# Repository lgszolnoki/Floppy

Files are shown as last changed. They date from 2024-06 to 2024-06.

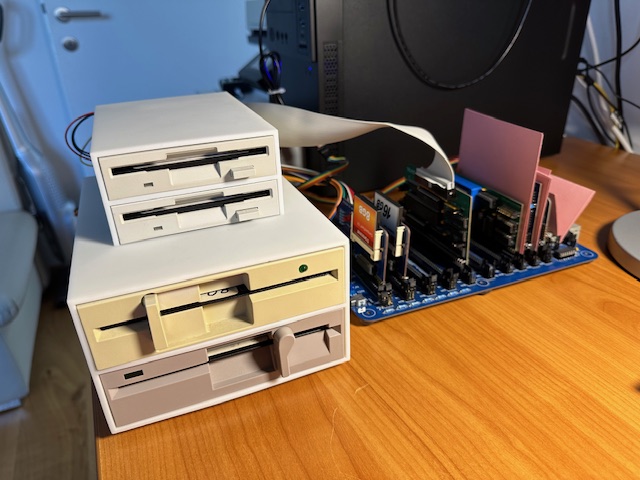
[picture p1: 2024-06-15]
enclosure/testbed.jpg

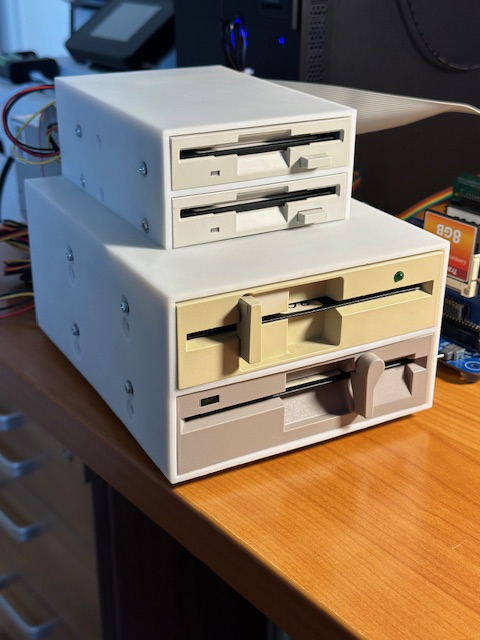
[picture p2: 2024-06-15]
enclosure/front.jpg

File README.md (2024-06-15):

**Floppy ReadMe** \
Laszlo Szolnoki  ([test@szolnoki.eu](mailto:test@szolnoki.eu)) \
15 June 2024

# Overview

2023 I got a couple of 5.25" floppy disk from the late 80s. All used in earlier PCs built in the GDR with corresponding formating. 
My first attempts to hande them with a modern PC failed. So I decided to build a CP/M 2.2 based retro computer. 
I learned RomWBW and was immediately determined to use it as my software base. # Overview

# Floppy

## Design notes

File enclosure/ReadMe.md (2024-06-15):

# Enclosure for 4 floppy drives
The enclosure is designed to house 4 floppy drives, 2 x 3.5" and 2 x 5.25" drives.  
I used Fusion360 to create it.

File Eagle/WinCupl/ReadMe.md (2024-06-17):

There are two ATF22V10C-15PU PLDs on the board. One for the address and buffer control and one for the floppy interface. FDC9266PLD.PLD is the file for the address control and FDC9266S.PLD for the floppy interface. The corresponding compiled files for the programming device are those with the extension *.jed.

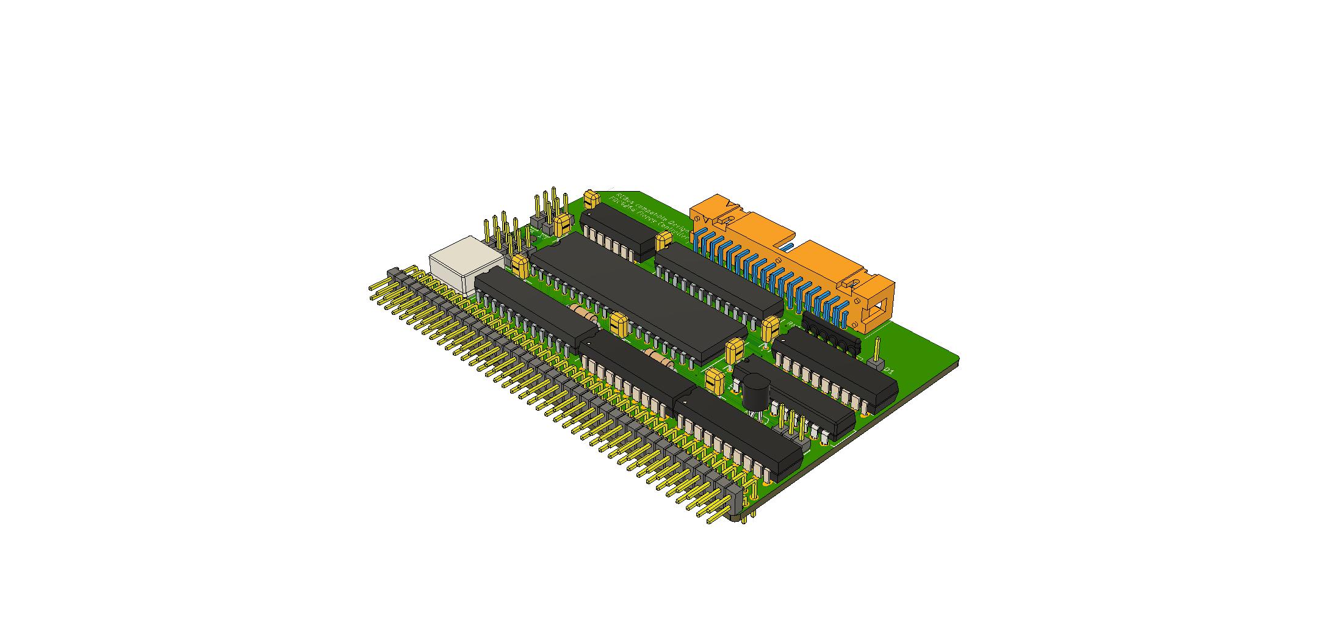
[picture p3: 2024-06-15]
enclosure/FDC9266_floppy.jpg

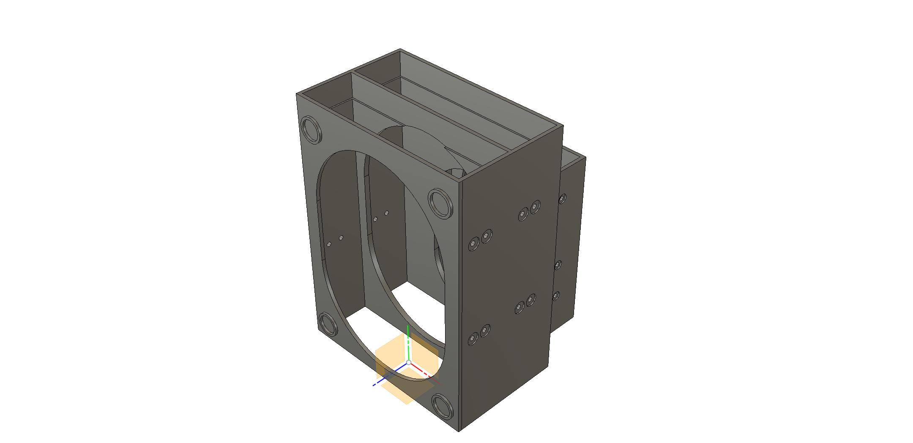
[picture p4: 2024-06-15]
enclosure/FloppyTower.jpg

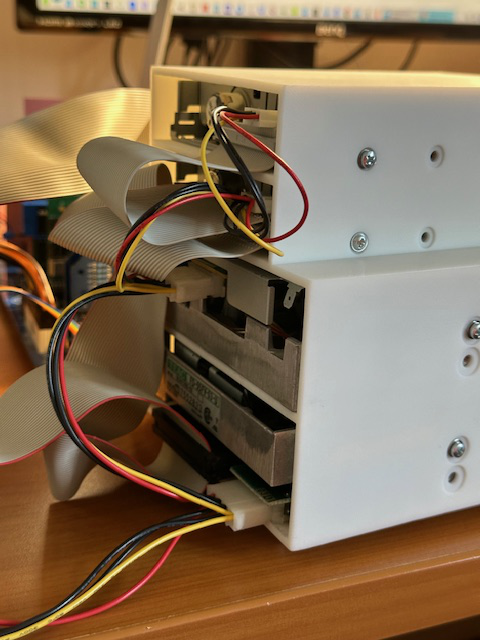
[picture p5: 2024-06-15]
enclosure/back.jpg

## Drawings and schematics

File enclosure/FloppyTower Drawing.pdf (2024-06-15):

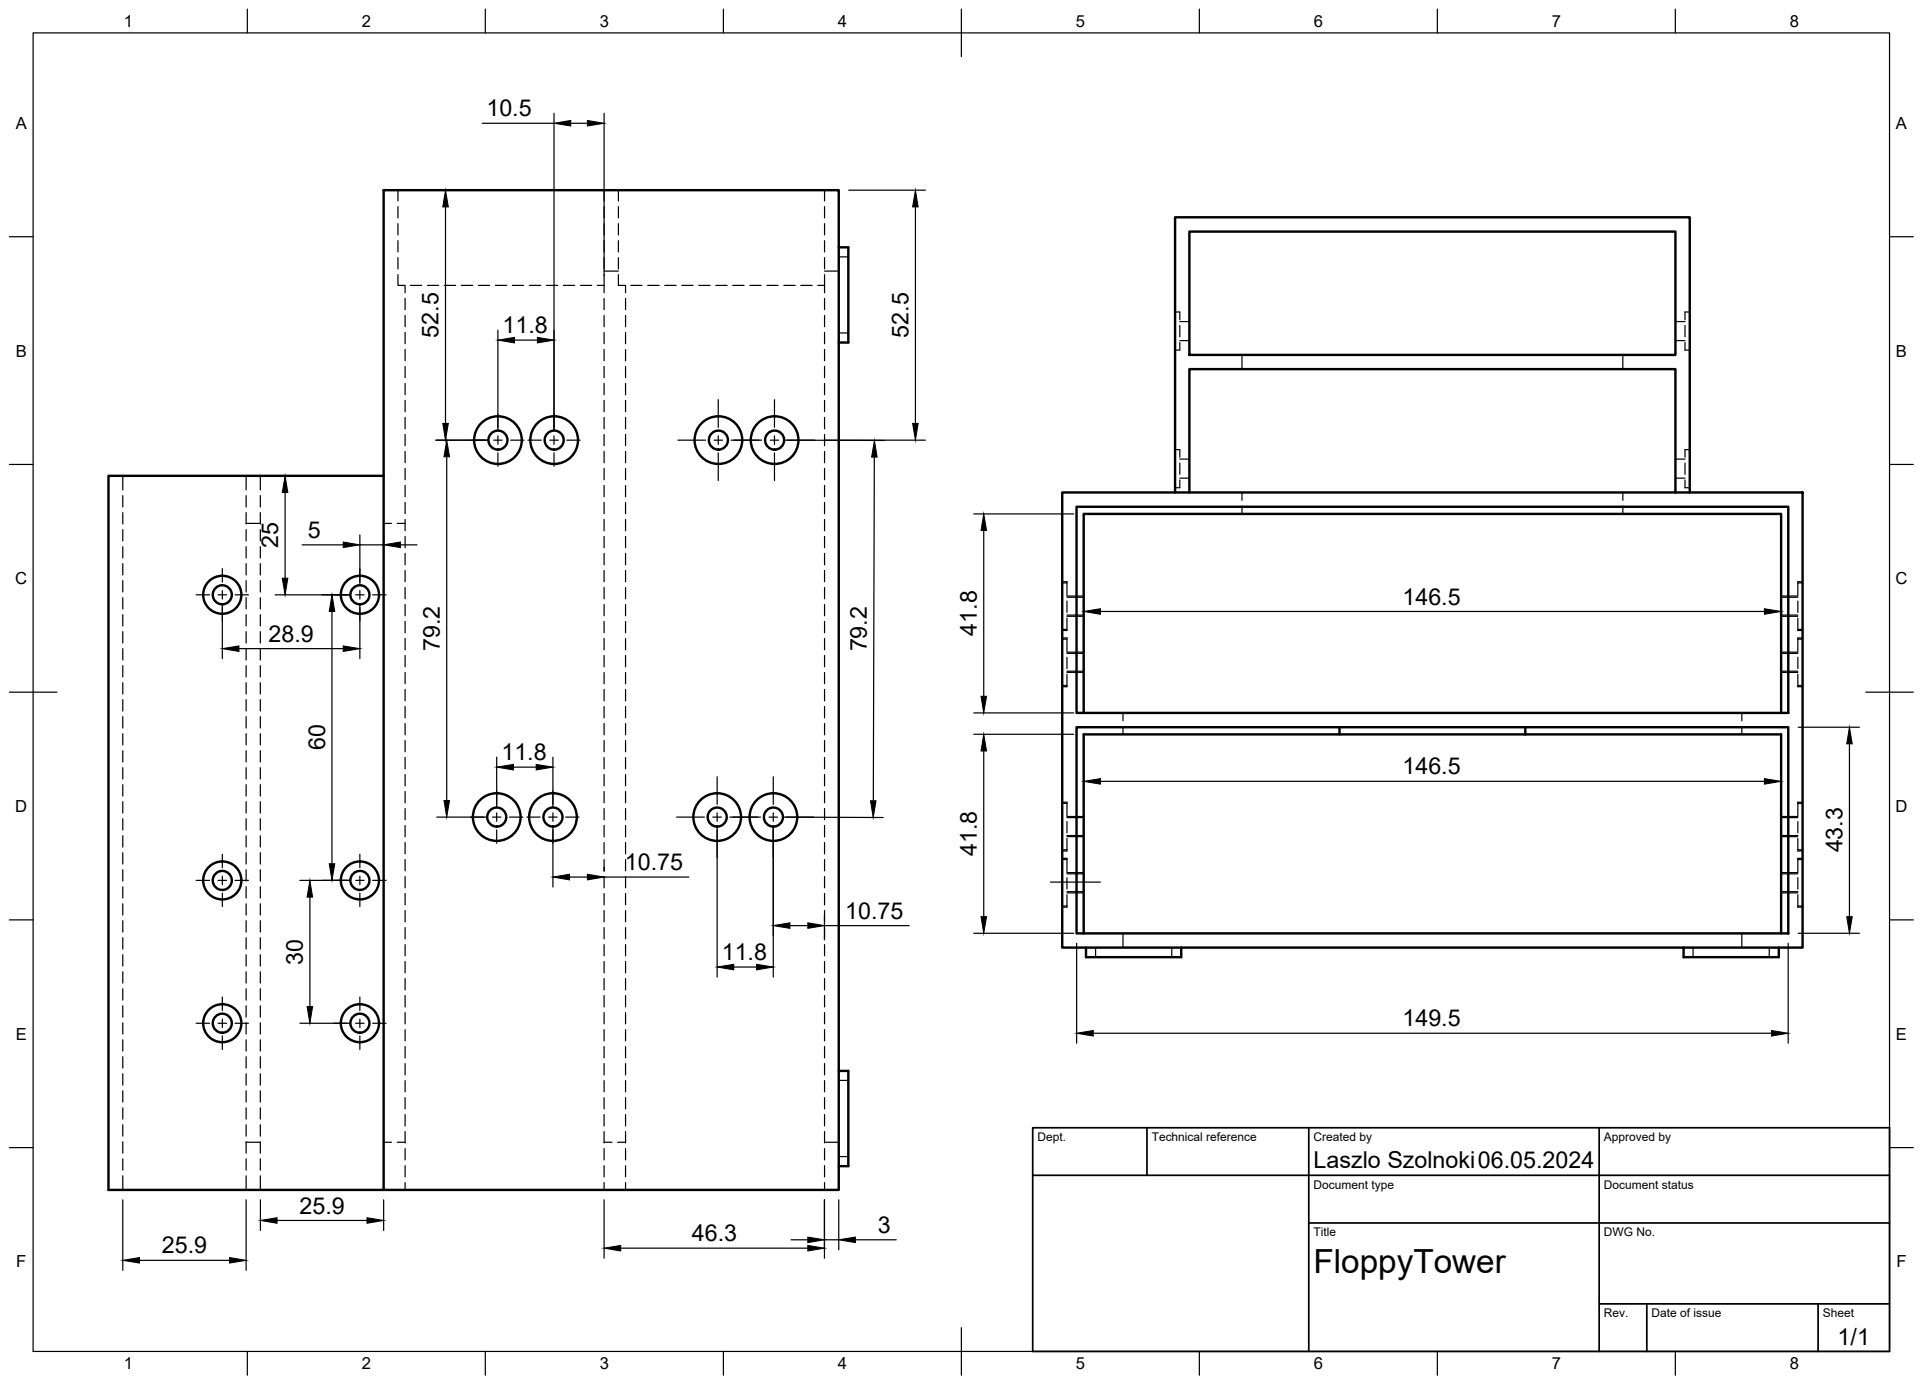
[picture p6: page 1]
Title; DWG No.; Rev.; Date of issue; Sheet; Laszlo Szolnoki 41.8

Dept. | Technical reference | Created by 06.05.2024 | Approved by

Document type | Document status

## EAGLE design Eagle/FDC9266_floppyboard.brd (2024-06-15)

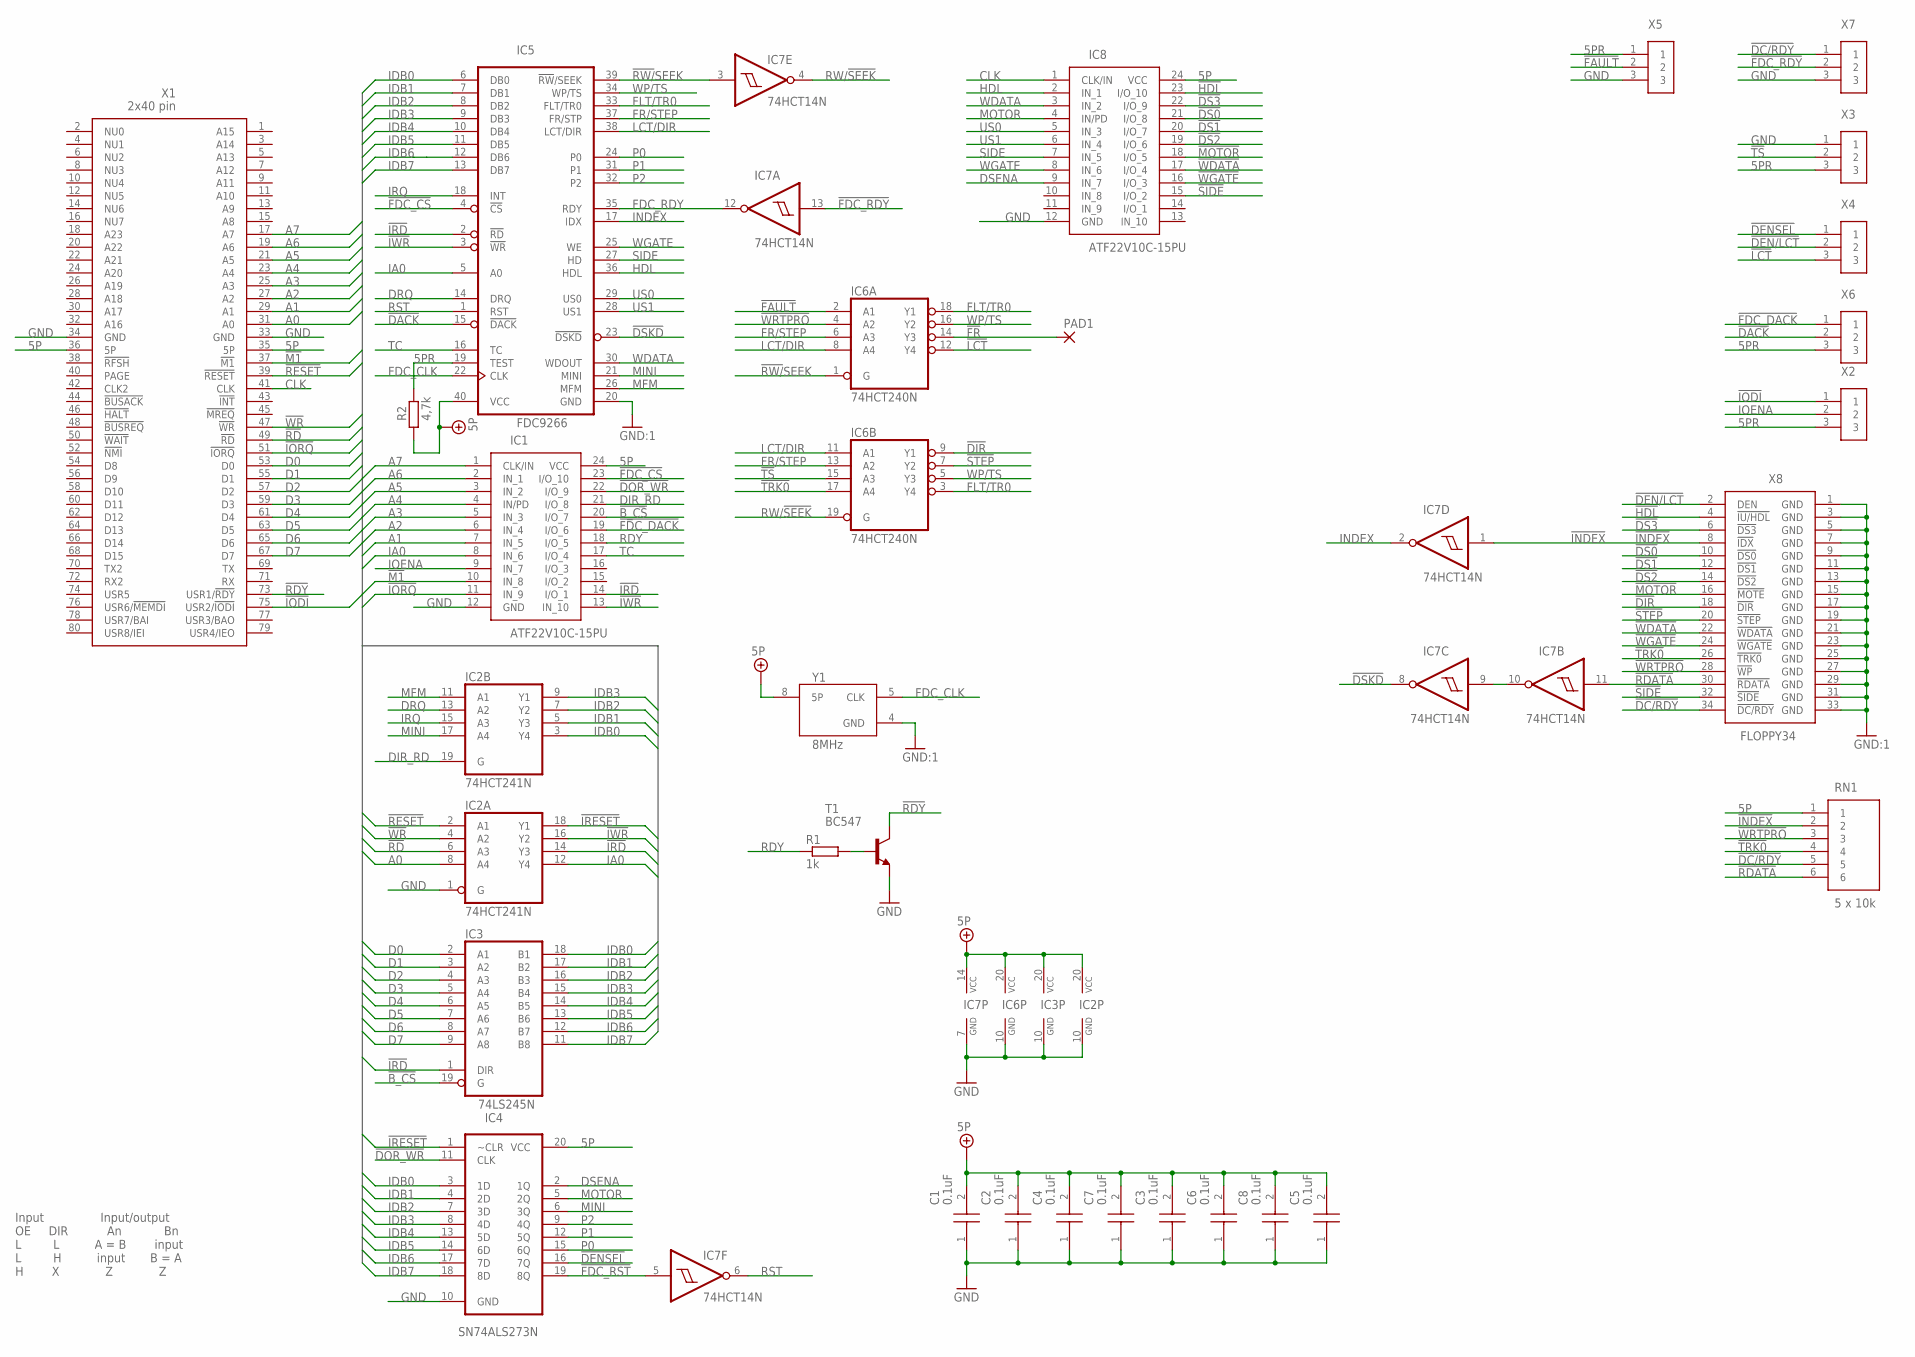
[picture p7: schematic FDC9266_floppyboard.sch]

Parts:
C1, C2, C3, C4, C5, C6, C7, C8: 0.1uF; C315C103K5R5TA7303
IC1, IC8: ATF22V10C-15PU; DIP794W56P254L3188H533Q24N
IC2: 74HCT241N; DIL20
IC3: 74LS245N; DIL20
IC4: SN74ALS273N; DIP254P762X508-20
IC5: FDC9266; DIP1550W53P254L5232H424Q40N
IC6: 74HCT240N; DIL20
IC7: 74HCT14N; DIL14
PAD1: WIREPAD1,6/0,8; 1,6/0,8
R1: 1k; 0207/10
R2: 4,7k; 0207/10
RN1: 5 x 10k; 4606X102103LF
T1: BC547; TO92
X1: 2x40 pin; RC2014_80_RA
X2, X3, X4, X5, X6, X7: TSW-103-07-G-S07; TSW-103-XX-G-S
X8: FLOPPY34; 09185346323
Y1: 8MHz; ECS-2100AX-200

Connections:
5P: C1.2, C2.2, C3.2, C4.2, C5.2, C6.2, C7.2, C8.2, IC1.24 (VCC), IC2.20 (VCC), IC3.20 (VCC), IC4.20 (VCC), IC5.40 (VCC), IC6.20 (VCC), IC7.14 (VCC), IC8.24 (VCC), R2.1, RN1.1, X1.35 (5P), X1.36 (5P), Y1.8 (5P)
5PR: IC5.19 (TEST), R2.2, X2.3, X3.3, X5.1, X6.3
!B_CS: IC1.20 (I/O_7), IC3.19 (G)
!DACK: IC5.15 (!DACK), X6.2
!DC/RDY: RN1.5, X7.1, X8.34 (!DC/RDY)
!DEN/LCT: X4.2, X8.2 (DEN)
!DENSEL: IC4.16 (7Q), X4.1
!DIR: IC6.9 (Y1), X8.18 (!DIR)
!DOR_WR: IC1.22 (I/O_9), IC4.11 (CLK)
!DS0: IC8.21 (I/O_8), X8.10 (!DS0)
!DS1: IC8.20 (I/O_7), X8.12 (!DS1)
!DS2: IC8.19 (I/O_6), X8.14 (!DS2)
!DS3: IC8.22 (I/O_9), X8.6 (!DS3)
!DSKD: IC5.23 (!DSKD), IC7.8 (O)
!FAULT: IC6.2 (A1), X5.2
!FDC_CS: IC1.23 (I/O_10), IC5.4 (!CS)
!FDC_DACK: IC1.19 (I/O_6), X6.1
!FDC_RDY: IC7.13 (I), X7.2
!FDC_RST: IC4.19 (8Q), IC7.5 (I)
!FR: IC6.14 (Y3), PAD1.1
!HDL: IC8.23 (I/O_10), X8.4 (!IU/HDL)
!INDEX: IC7.1 (I), RN1.2, X8.8 (!IDX)
!IODI: X1.75 (USR2/!IODI), X2.1
!IORQ: IC1.11 (IN_9), X1.51 (!IORQ)
!IRD: IC1.14 (I/O_1), IC2.14 (Y3), IC3.1 (DIR), IC5.2 (!RD)
!IRESET: IC2.18 (Y1), IC4.1 (~CLR)
!IWR: IC1.13 (IN_10), IC2.16 (Y2), IC5.3 (!WR)
!LCT: IC6.12 (Y4), X4.3
!M1: IC1.10 (IN_8), X1.37 (!M1)
!MOTOR: IC8.18 (I/O_5), X8.16 (!MOTE)
!RD: IC2.6 (A3), X1.49 (!RD)
!RDATA: IC7.11 (I), RN1.6, X8.30 (!RDATA)
!RDY: T1.3 (C), X1.73 (USR1/!RDY)
!RESET: IC2.2 (A1), X1.39 (!RESET)
!RW/!SEEK: IC5.39 (!RW!/SEEK), IC6.1 (G), IC7.3 (I)
!SIDE: IC8.15 (I/O_2), X8.32 (!SIDE)
!STEP: IC6.7 (Y2), X8.20 (!STEP)
!TRK0: IC6.17 (A4), RN1.4, X8.26 (!TRK0)
!TS: IC6.15 (A3), X3.2
!WDATA: IC8.17 (I/O_4), X8.22 (!WDATA)
!WGATE: IC8.16 (I/O_3), X8.24 (!WGATE)
!WR: IC2.4 (A2), X1.47 (!WR)
!WRTPRO: IC6.4 (A2), RN1.3, X8.28 (!WP)
A0: IC2.8 (A4), X1.31 (A0)
A1: IC1.7 (IN_5), X1.29 (A1)
A2: IC1.6 (IN_4), X1.27 (A2)
A3: IC1.5 (IN_3), X1.25 (A3)
A4: IC1.4 (IN/PD), X1.23 (A4)
A5: IC1.3 (IN_2), X1.21 (A5)
A6: IC1.2 (IN_1), X1.19 (A6)
A7: IC1.1 (CLK/IN), X1.17 (A7)
CLK: IC8.1 (CLK/IN), X1.41 (CLK)
D0: IC3.2 (A1), X1.53 (D0)
D1: IC3.3 (A2), X1.55 (D1)
D2: IC3.4 (A3), X1.57 (D2)
D3: IC3.5 (A4), X1.59 (D3)
D4: IC3.6 (A5), X1.61 (D4)
D5: IC3.7 (A6), X1.63 (D5)
D6: IC3.8 (A7), X1.65 (D6)
D7: IC3.9 (A8), X1.67 (D7)
DIR_RD: IC1.21 (I/O_8), IC2.19 (G)
DRQ: IC2.13 (A2), IC5.14 (DRQ)
DSENA: IC4.2 (1Q), IC8.9 (IN_7)
FDC_CLK: IC5.22 (CLK), Y1.5 (CLK)
FDC_RDY: IC5.35 (RDY), IC7.12 (O)
FLT/TR0: IC5.33 (FLT/TR0), IC6.3 (Y4), IC6.18 (Y1)
FR/STEP: IC5.37 (FR/STP), IC6.6 (A3), IC6.13 (A2)
GND: C1.1, C2.1, C3.1, C4.1, C5.1, C6.1, C7.1, C8.1, IC1.12 (GND), IC2.1 (G), IC2.10 (GND), IC3.10 (GND), IC4.10 (GND), IC5.20 (GND), IC6.10 (GND), IC7.7 (GND), IC8.12 (GND), T1.1 (E), X1.33 (GND), X1.34 (GND), X3.1, X5.3, X7.3, X8.1 (GND), X8.3 (GND), X8.5 (GND), X8.7 (GND), X8.9 (GND), X8.11 (GND), X8.13 (GND), X8.15 (GND), X8.17 (GND), X8.19 (GND), X8.21 (GND), X8.23 (GND), X8.25 (GND), X8.27 (GND), X8.29 (GND), X8.31 (GND), X8.33 (GND), Y1.4 (GND)
HDL: IC5.36 (HDL), IC8.2 (IN_1)
IA0: IC1.8 (IN_6), IC2.12 (Y4), IC5.5 (A0)
IDB0: IC2.3 (Y4), IC3.18 (B1), IC4.3 (1D), IC5.6 (DB0)
IDB1: IC2.5 (Y3), IC3.17 (B2), IC4.4 (2D), IC5.7 (DB1)
IDB2: IC2.7 (Y2), IC3.16 (B3), IC4.7 (3D), IC5.8 (DB2)
IDB3: IC2.9 (Y1), IC3.15 (B4), IC4.8 (4D), IC5.9 (DB3)
IDB4: IC3.14 (B5), IC4.13 (5D), IC5.10 (DB4)
IDB5: IC3.13 (B6), IC4.14 (6D), IC5.11 (DB5)
IDB6: IC3.12 (B7), IC4.17 (7D), IC5.12 (DB6)
IDB7: IC3.11 (B8), IC4.18 (8D), IC5.13 (DB7)
INDEX: IC5.17 (IDX), IC7.2 (O)
IOENA: IC1.9 (IN_7), X2.2
IRQ: IC2.15 (A3), IC5.18 (INT)
LCT/DIR: IC5.38 (LCT/DIR), IC6.8 (A4), IC6.11 (A1)
MFM: IC2.11 (A1), IC5.26 (MFM)
MINI: IC2.17 (A4), IC4.6 (3Q), IC5.21 (MINI)
MOTOR: IC4.5 (2Q), IC8.4 (IN/PD)
unnamed: IC7.9 (I), IC7.10 (O)
unnamed: R1.2, T1.2 (B)
P0: IC4.15 (6Q), IC5.24 (P0)
P1: IC4.12 (5Q), IC5.31 (P1)
P2: IC4.9 (4Q), IC5.32 (P2)
RDY: IC1.18 (I/O_5), R1.1
RST: IC5.1 (RST), IC7.6 (O)
RW/!SEEK: IC6.19 (G), IC7.4 (O)
SIDE: IC5.27 (HD), IC8.7 (IN_5)
TC: IC1.17 (I/O_4), IC5.16 (TC)
US0: IC5.29 (US0), IC8.5 (IN_3)
US1: IC5.28 (US1), IC8.6 (IN_4)
WDATA: IC5.30 (WDOUT), IC8.3 (IN_2)
WGATE: IC5.25 (WE), IC8.8 (IN_6)
WP/TS: IC5.34 (WP/TS), IC6.5 (Y3), IC6.16 (Y2)

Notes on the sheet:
Input Input/output OE DIR An Bn L L A = B input L H input B = A H X Z Z

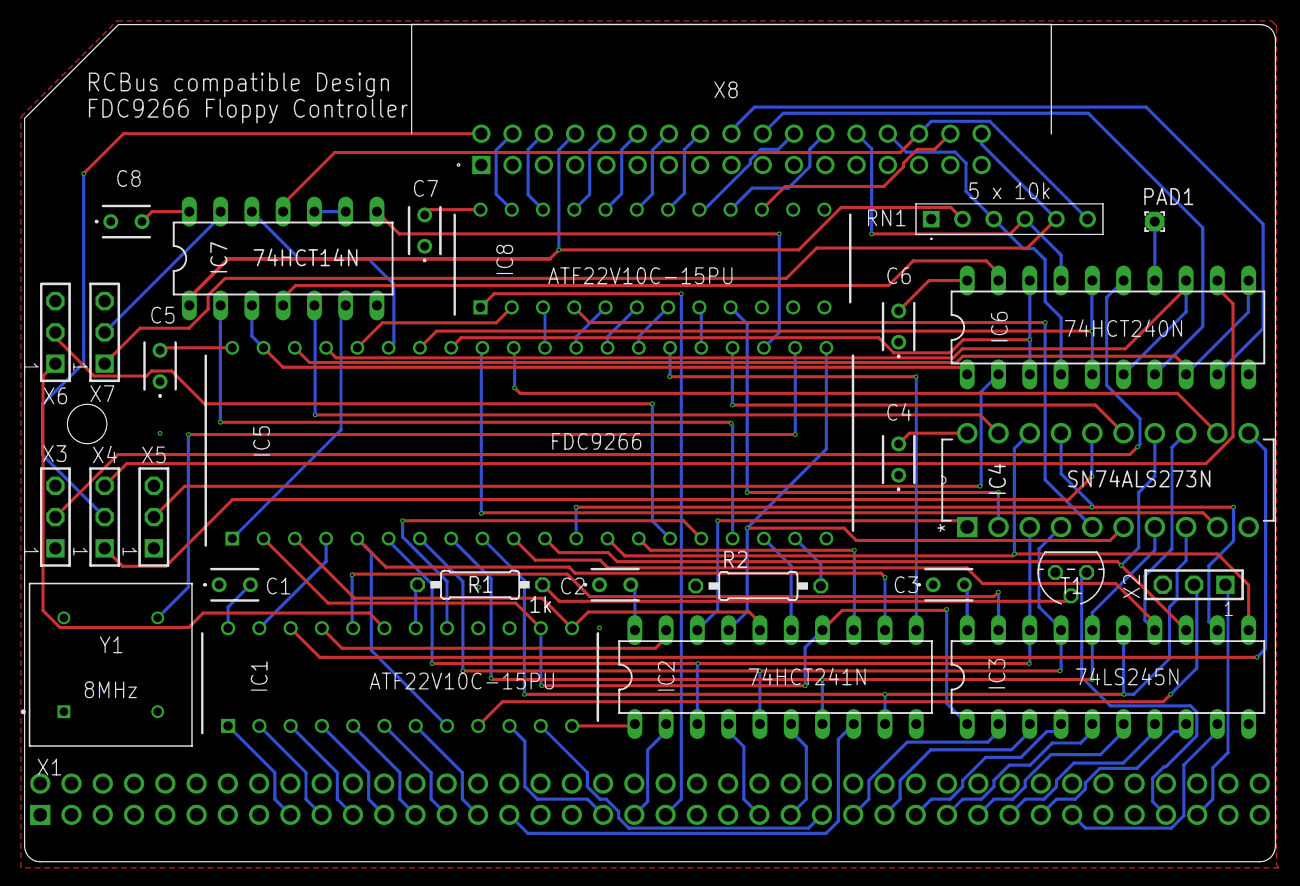
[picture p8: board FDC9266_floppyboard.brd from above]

Board: 4 copper layers, 101.6 x 68.0 mm, 30 parts (0 on the bottom side), 100 nets.

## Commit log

2024-06-15 Create enclosure
2024-06-17 Add files via upload
    final version
    [FDC9266_floppyboard.brd, FDC9266_floppyboard.sch]
